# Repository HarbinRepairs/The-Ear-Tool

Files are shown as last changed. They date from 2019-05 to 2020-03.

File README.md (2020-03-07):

# The Ear Tool

Model: ET-1

Get this kit at our store: http://bit.ly/2TQ3Cbr
Or on eBay: https://ebay.to/38sRZv4

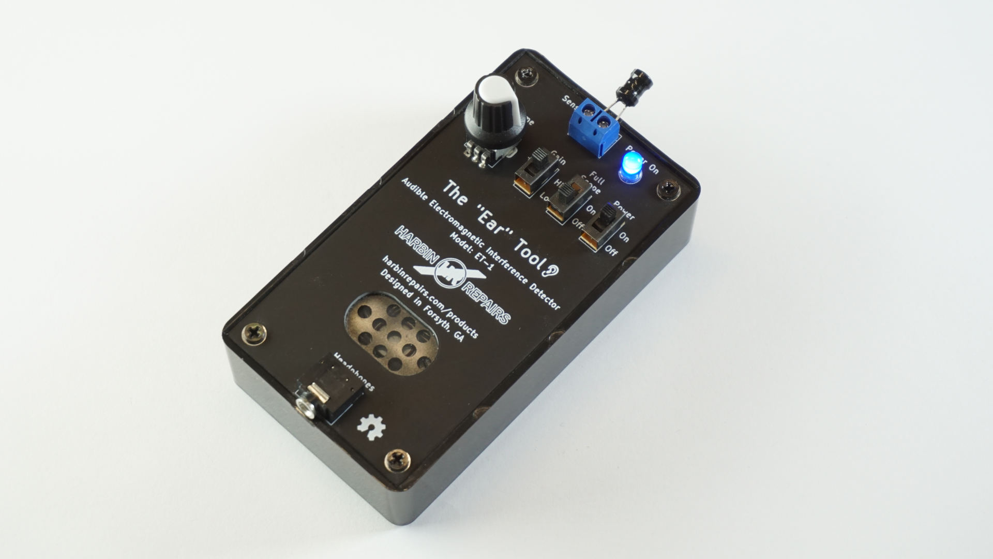
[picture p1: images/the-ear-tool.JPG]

materials

# License
Harbin Repairs 2020
Creative Commons Attribution ShareAlike 4.0
https://creativecommons.org/licenses/by-sa/4.0/

# Documentation

## What is the Ear tool?
The Ear tool can be used to detect almost any electromagnetic interference coming from your electronics such as a power supply, transformer, CPU, microcontroller, wireless transmitter, relays, switches, speakers, transducers, transistors and more. At Harbin Repairs we use the Ear Tool to diagnose problems with computer motherboards, cellphones, and televisions by pointing the tool at different parts of a circuit board and listening to the high frequency pulsing coming from different components. For example, this can help us determine if a CPU or microcontroller is doing any processing or if it’s just sitting there burning up because there’s a short somewhere. It can also let us know if a cellphone or other device is turning on even if there’s no sign of life on the screen or lights. The tool can also be used to discover the different noises your electronics make when they are doing different things (e.g. standby mode vs. fully powered on). For the controls, the gain switch adjusts between high and low sensor gain and the full scope switch switch is used to help clear up some of the background noise. More examples are in the assembly guide video below.
## Demonstration and kit assmebly guide Video

https://youtu.be/0QIx8OhJN-o

The Ear Tool Demo Video & Assembly (https://www.youtube.com/watch?v=0QIx8OhJN-o)

## Bill of Materials

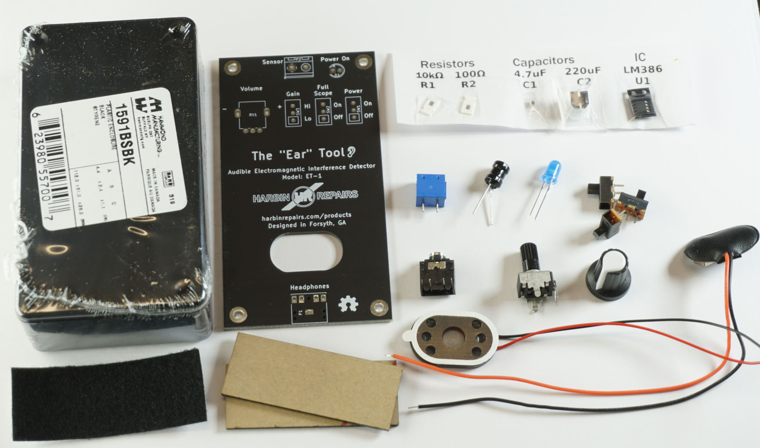
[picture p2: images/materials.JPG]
materials


| Description | Part # | Main Links (Affiliate) | eBay Links (Affiliate)  | Amazon Links (Affiliate) |
|---|---|---|---|---|
| PCB | N/A | PCB manufacturer of choice  | N/A | N/A |
| Enclosure | 1591BSBK | https://bit.ly/2sKEk3i | https://ebay.to/30SXp05 | https://amzn.to/2um65Qa  |
| Speaker | 1.5W8R 8R1.5W | https://bit.ly/2upP8nP | https://ebay.to/36eXlbX | N/A |
| 100Ω Resistor 0805 | N/A | https://bit.ly/2TKRSqF | https://ebay.to/2ul6eDt | N/A |
| 1kΩ Resistor 0805 | N/A | https://bit.ly/36lOaql | https://ebay.to/2TNRTtY | N/A |
| 220uf Electrolytic Capacitor  | N/A | https://bit.ly/2RxIeEY | https://ebay.to/2RHrTh0 | N/A |
| 4.7uf Ceramic Capacitor 0805  | N/A | https://bit.ly/3awu9k3 | https://ebay.to/36lOJ3r | N/A |
| Blue LED 5mm | N/A | https://bit.ly/2GgnU5K | https://ebay.to/37h1f5p | https://amzn.to/37sNP6c  |
| LM386 Audio Amp | LM386 | https://bit.ly/2tweNeR | https://ebay.to/2RHXmA1 | N/A |
| SPST Slide Switch THT | SS12F17G4 | https://bit.ly/30IrAqm | https://ebay.to/30MXx14 | N/A |
| 3.5mm Headphone Jack | 307 3F07 | https://bit.ly/36hQ5Mu | https://ebay.to/36eJQcm | https://amzn.to/36eYmRj  |
| 100mH Inductor | N/A | https://bit.ly/38xpU63 | https://ebay.to/36eJQJo | https://amzn.to/2TNTjoi  |
| Felt Tape | JVCC FELT-065 | https://ebay.to/2G9WzlS | https://ebay.to/2G9WzlS | https://amzn.to/30JB05h  |
| Battery Compartment Separator | Custom Laser Cut | https://www.delviesplastics.com/ | Drawings available on Github | N/A |
| 9v Battery Clip | N/A | https://bit.ly/2RfzFjh | https://ebay.to/2uis6zx | https://amzn.to/2TKSEnB  |
| 10KΩ Potentiometer | B103 10K 0932 WH09 | https://bit.ly/2ul666X | https://ebay.to/2NRkgno | N/A |
| Pot Knob 15mm x 17mm x 6mm | N/A | https://bit.ly/37f6bYo | https://ebay.to/37jvYim | https://amzn.to/2GawAur  |
| Terminal Block Connector | KF301-5.0-2P | https://bit.ly/38xsJnF | https://ebay.to/3avkOZG | https://amzn.to/369tQZ2  |

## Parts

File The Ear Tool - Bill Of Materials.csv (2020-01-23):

Description | Part # | Main Links (Affiliate) | eBay Links (Affiliate) | Amazon Links (Affiliate)
PCB | N/A | PCB manufacturer of choice | N/A | N/A
Enclosure | 1591BSBK | http://bit.ly/2sKEk3i | https://ebay.to/30SXp05 | https://amzn.to/2um65Qa
Speaker | 1.5W8R 8R1.5W | http://bit.ly/2upP8nP | https://ebay.to/36eXlbX | N/A
100Ω Resistor 0805 | N/A | http://bit.ly/2TKRSqF | https://ebay.to/2ul6eDt | N/A
1kΩ Resistor 0805 | N/A | http://bit.ly/36lOaql | https://ebay.to/2TNRTtY | N/A
220uf Electrolytic Capacitor | N/A | http://bit.ly/2RxIeEY | https://ebay.to/2RHrTh0 | N/A
4.7uf Ceramic Capacitor | N/A | http://bit.ly/3awu9k3 | https://ebay.to/36lOJ3r | N/A
Blue LED 5mm | N/A | http://bit.ly/2GgnU5K | https://ebay.to/37h1f5p | https://amzn.to/37sNP6c
LM386 Audio Amp | LM386 | http://bit.ly/2tweNeR | https://ebay.to/2RHXmA1 | N/A
SPST Slide Switch THT | SS12F17G4 | http://bit.ly/30IrAqm | https://ebay.to/30MXx14 | N/A
3.5mm Headphone Jack | 307 3F07 | http://bit.ly/36hQ5Mu | https://ebay.to/36eJQcm | https://amzn.to/36eYmRj
100mH Inductor | N/A | http://bit.ly/38xpU63 | https://ebay.to/36eJQJo | https://amzn.to/2TNTjoi
Felt Tape | JVCC FELT-065 | https://ebay.to/2G9WzlS | https://ebay.to/2G9WzlS | https://amzn.to/30JB05h
Battery Compartment Separator | Custom Laser Cut | Drawings on github | N/A | N/A
9v Battery Clip | N/A | http://bit.ly/2RfzFjh | https://ebay.to/2uis6zx | https://amzn.to/2TKSEnB
10KΩ Potentiometer | B103 10K 0932 WH09 | http://bit.ly/2ul666X | https://ebay.to/2NRkgno | N/A
Pot Knob 15mm*17mm*6mm | N/A | http://bit.ly/37f6bYo | https://ebay.to/37jvYim | https://amzn.to/2GawAur
Terminal Block Connector | KF301-5.0-2P | http://bit.ly/38xsJnF | https://ebay.to/3avkOZG | https://amzn.to/369tQZ2

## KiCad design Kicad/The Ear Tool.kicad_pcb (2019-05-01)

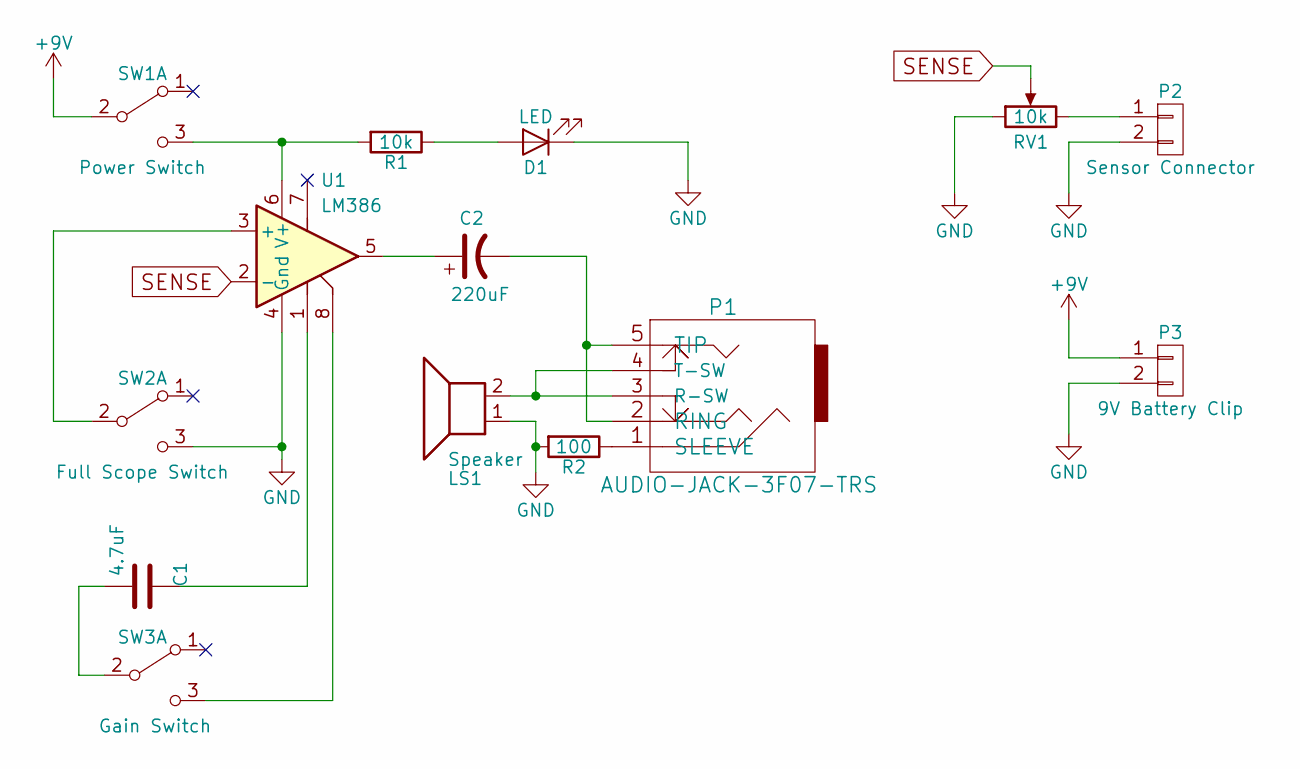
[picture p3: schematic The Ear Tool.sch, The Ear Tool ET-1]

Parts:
C1: 4.7uF; C_0805_HandSoldering
C2: 220uF; C_Radial_D5_L6_P2.5
D1: LED; C_0805
LS1: Speaker; NetTie-I_SMD
P1: AUDIO-JACK-3F07-TRS
P2: Sensor Connector; NetTie-I_SMD
P3: 9V Battery Clip; NetTie-I_SMD
R1: 10k; R_0805_HandSoldering
R2: 100; R_0805_HandSoldering
RV1: 10k; POT_RV09_HORIZONTAL_WHO9
SW1: Power Switch; SW_SPDT_3P_11.1mm_5.5mm
SW2: Full Scope Switch; SW_SPDT_3P_11.1mm_5.5mm
SW3: Gain Switch; SW_SPDT_3P_11.1mm_5.5mm
U1: LM386; SOIC-8-N

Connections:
+9V: P3.1, SW1.2 (B)
GND: D1.1 (K), LS1.1, P2.2, P3.2, R2.2, RV1.1, SW2.3 (C), U1.4 (Gnd)
unnamed: C1.1, U1.1
unnamed: C1.2, SW3.2 (B)
unnamed: C2.1, U1.5
unnamed: C2.2, P1.2 (RING), P1.5 (TIP)
unnamed: D1.2 (A), R1.1
unnamed: LS1.2, P1.3 (R-SW), P1.4 (T-SW)
unnamed: P1.1 (SLEEVE), R2.1
unnamed: P2.1, RV1.3
unnamed: R1.2, SW1.3 (C), U1.6 (V+)
unnamed: SW2.2 (B), U1.3 (+)
unnamed: SW3.3 (C), U1.8
SENSE: RV1.2, U1.2 (-)

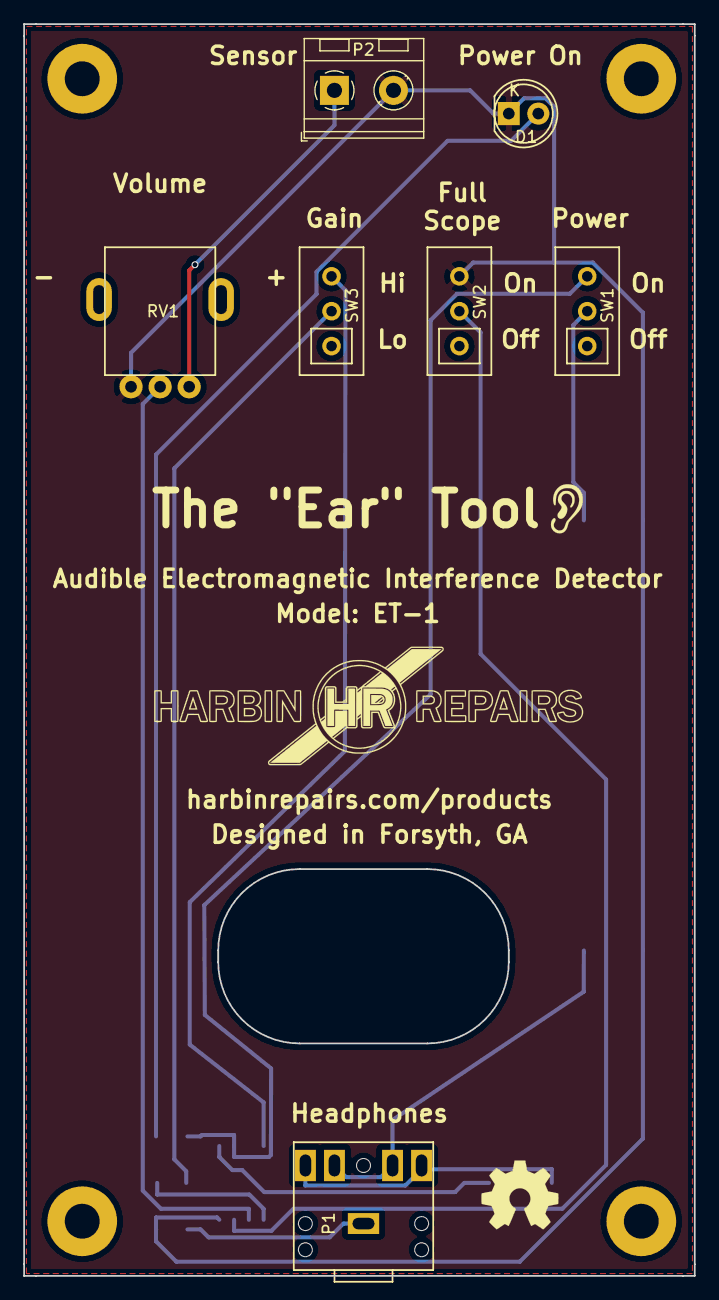
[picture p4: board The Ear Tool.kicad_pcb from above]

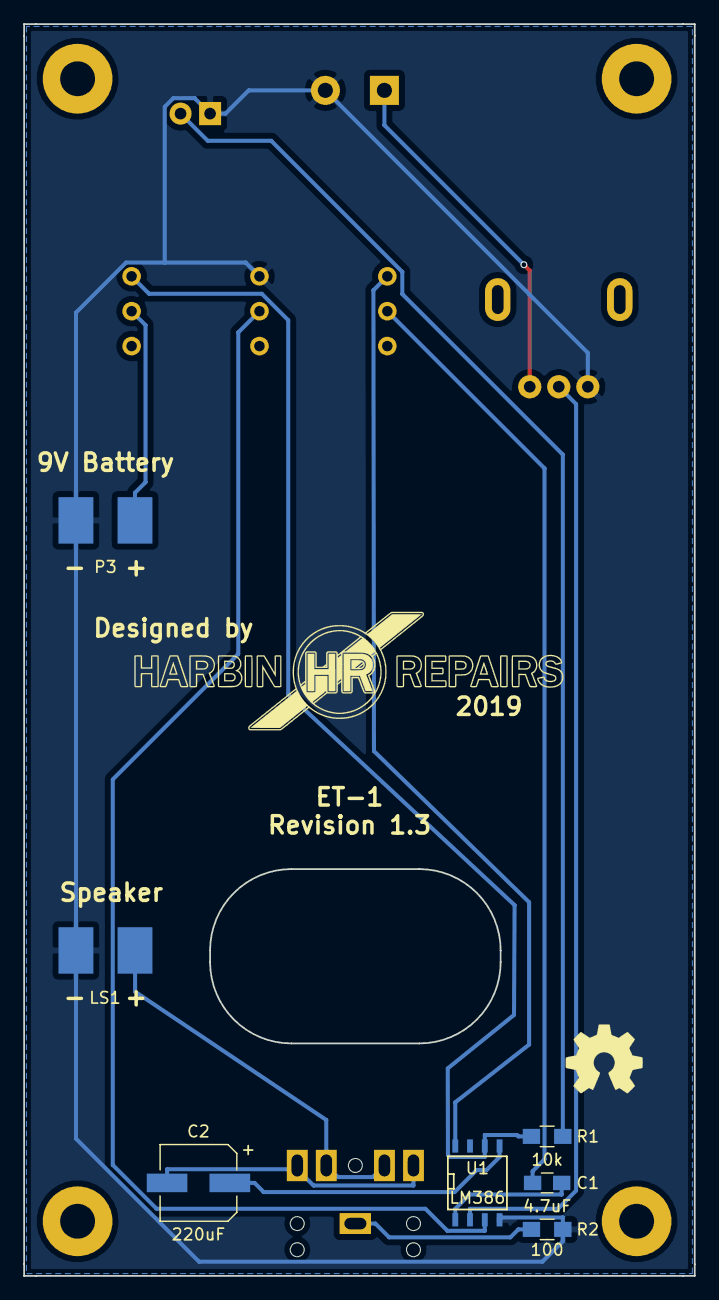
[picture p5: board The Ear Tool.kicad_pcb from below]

Board: 2 copper layers, 57.7 x 107.7 mm, 21 parts (8 on the bottom side), 14 nets.

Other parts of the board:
G1, G2: LOGO; HR_LOGO_37.4x10.6mm
G3: LOGO; Ear_icon_4.2x4.2mm
M1, M2, M3, M4: MountingHole_3mm_Pad

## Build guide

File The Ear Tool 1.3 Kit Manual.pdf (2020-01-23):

# Thank you for your purchase!

# Scan Here

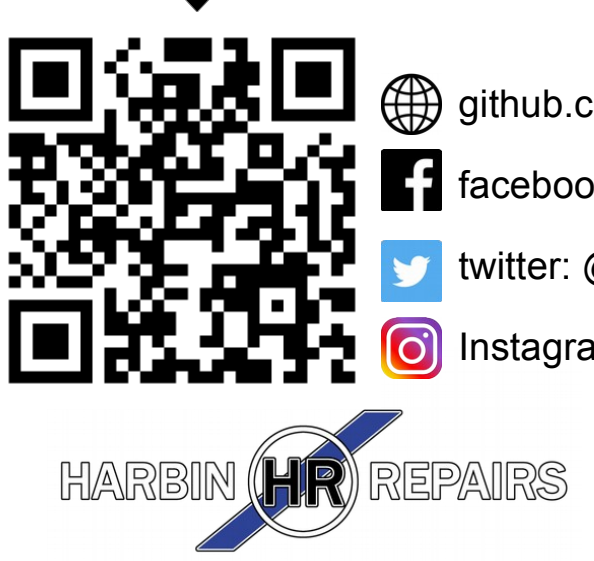
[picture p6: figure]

github.com/harbinrepairs

facebook.com/HarbinRepairs

twitter: @harbin_repairs

Instagram: @harbinrepairs

# The Ear Tool

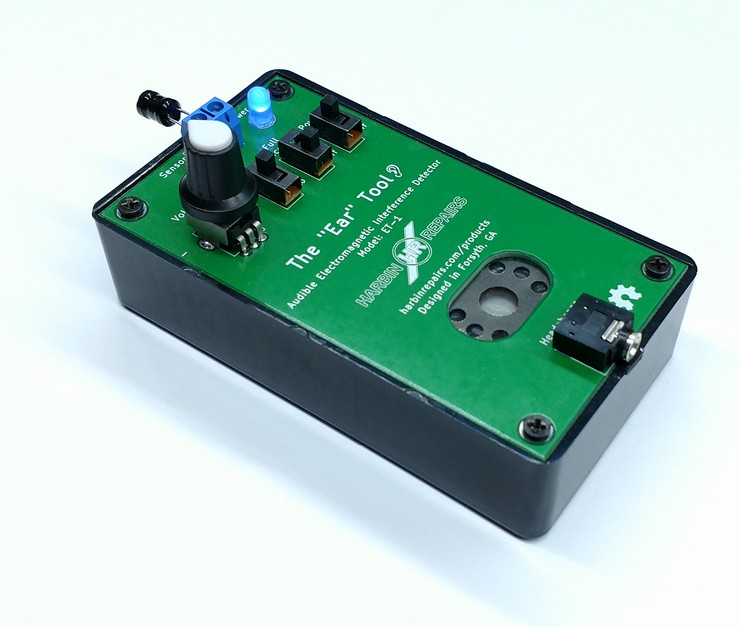
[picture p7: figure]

## Model: ET-1 Kit

with your smartphone for
assembly video,
schematics, bill of
materials, and more info.

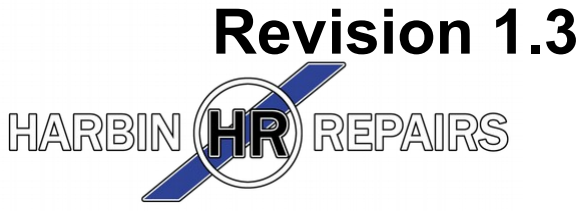
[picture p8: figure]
Revision 1.3

- Usage - | - Diagram -

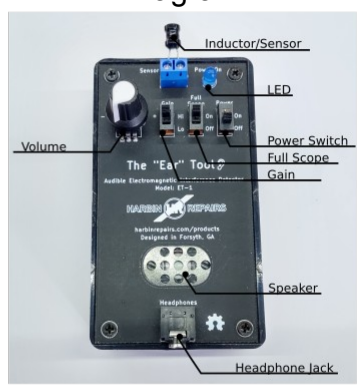
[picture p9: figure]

The Ear tool can be used to detect almost any electromagnetic interference coming from your electronics such as a power supply, transformer, CPU, microcontroller, wireless transmitter, relays, switches, speakers, transducers, transistors and more. At Harbin Repairs we use the Ear Tool to diagnose problems with computer motherboards, cellphones, and televisions by pointing the tool at different parts of a circuit board and listening to the high frequency pulsing coming from different components. For example, this can help us determine if a CPU or microcontroller is doing any processing or if it’s just sitting there burning up because there’s a short somewhere. It can also let us know if a cellphone or other device is turning on even if there’s no sign of life on the screen or lights. The tool can also be used to discover the different noises your electronics make when they are doing different things (e.g. standby mode vs. fully powered on). For the controls, the gain switch adjusts between high and low sensor gain and the full scope switch switch is used to help clear up some of the background noise. More information and assembly guide video can be found here: github.com/harbinrepairs/the-ear-tool

# - Package Contents -

1 – Enclosure 1 – The Ear Tool v1.3 PCB 1 – 9v Battery Clip 1 – 8Ω 1W Speaker 1 – 220uF Electrolytic Capacitor 1 – 4.7uF 0805 Ceramic Capacitor 1 – 10kΩ 0805 Resistor 1 – 100Ω 0805 Resistor 1 – LM386 Amplifier IC 1 – 10kΩ Potentiometer 3 – 2p Slide Switch 1 – 3.5mm Headphone Jack 1 – 5mm Blue LED 1 – 2 Pin Terminal Connector 1 – 100mH Inductor 2 – Battery Compartment Separator 1 – Adhesive Fabric

Note: 9V battery not included.
